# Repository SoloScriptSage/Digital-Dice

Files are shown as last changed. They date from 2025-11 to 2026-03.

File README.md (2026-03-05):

# 🎲 Digital Dice

A hardware random number generator built entirely from discrete logic ICs — no microcontroller, no code. Press the button, get a random number from 1 to 6 on a 7-segment display.

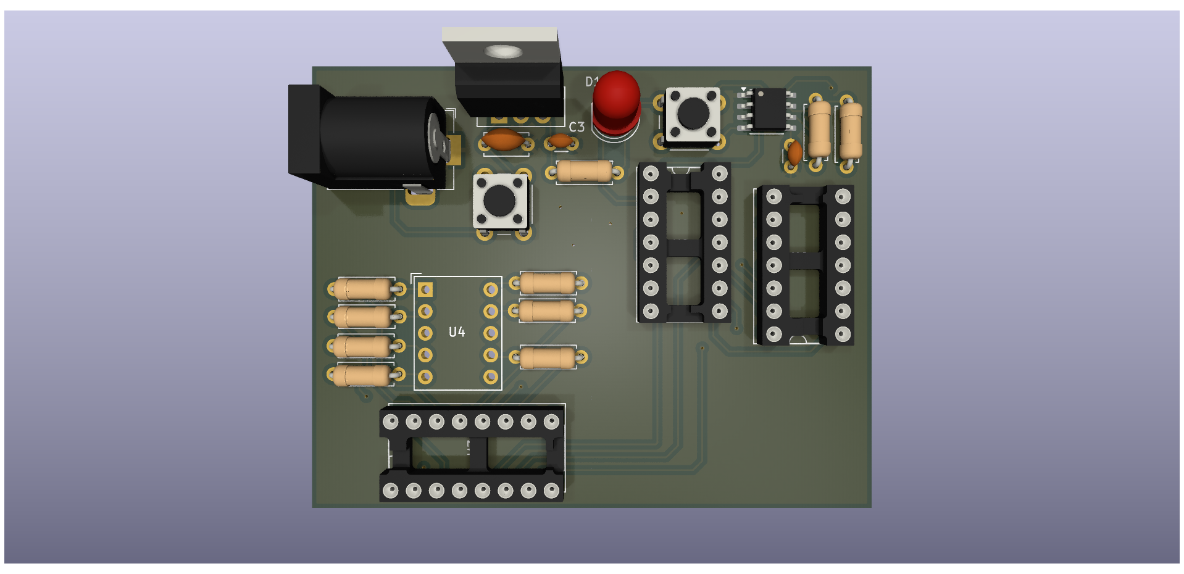
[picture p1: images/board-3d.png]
Schematic


---

## How It Works

The circuit is split into four sections:

```
[Power Supply] → [555 Timer Oscillator] → [74LS90 Counter] → [74LS47 BCD Decoder] → [7-Segment Display]
```

**1. Power Supply (LM7805)**
Accepts any DC input (7–35V via barrel jack) and regulates it down to a stable 5V. Decoupling capacitors filter noise on the supply line.

**2. Clock Generator (NE555 in astable mode)**
The 555 timer oscillates continuously, generating a fast clock signal. While the button is not pressed, the counter increments at high speed — too fast for the eye to track, which creates the randomness.

**3. Counter / Random Number Generator (74LS90)**
A 4-bit BCD counter that cycles 0→9. A NAND gate feedback loop (74LS11) resets it at 6, so it only counts 0–5 (displayed as 1–6). When the button is released, the counter freezes at whatever value it landed on.

**4. BCD Decoder + Display (74LS47 + SC39-11EWA)**
The 74LS47 converts the binary counter output into the 7 segment drive signals. A 220Ω current-limiting resistor protects the display segments.

---

## Components

| Component | Part | Purpose |
|---|---|---|
| U1 | NE555D | Astable oscillator (clock) |
| U2 | 74LS90 | 4-bit BCD counter |
| U3 | 74LS47 | BCD to 7-segment decoder |
| U4 | SC39-11EWA | Common cathode 7-segment display |
| U5 | LM7805 | 5V linear voltage regulator |
| U6A/D | 74LS11 | Triple 3-input AND gate (reset logic) |
| SW1 | SPST | Roll button |
| SW2 | SPST | Power switch |
| R1 | 10kΩ | 555 timing resistor |
| R5 | 220Ω | Display current limiter |
| R10 | 100kΩ | 555 timing resistor |
| J1 | Barrel Jack | DC power input |

---

## Schematic

Designed in **KiCad 9.0.2**. Full schematic and PCB layout files included in the repository.

---

## What I Learned

- Astable 555 timer configuration and RC timing calculations
- 4-bit BCD counter operation and modulo-N reset using gate feedback
- BCD to 7-segment decoding without a microcontroller
- PCB layout for mixed digital/analog circuits in KiCad

---

## Author

**Vladyslav Hirchuk** — [GitHub](https://github.com/SoloScriptSage) · [LinkedIn](https://linkedin.com/in/vladyslavhirchuk)

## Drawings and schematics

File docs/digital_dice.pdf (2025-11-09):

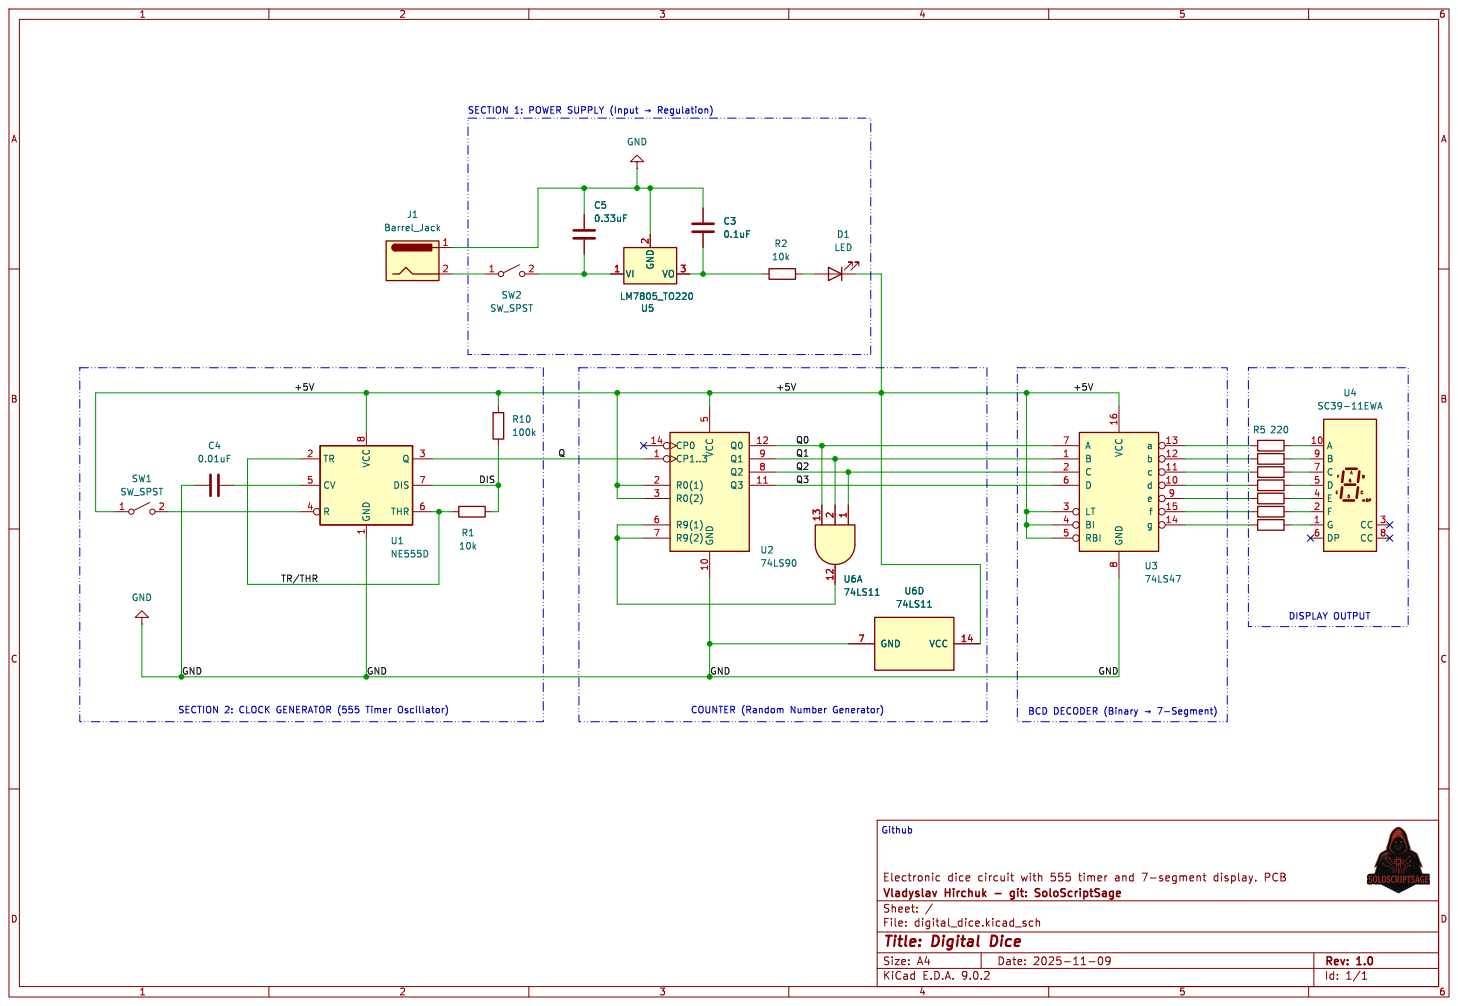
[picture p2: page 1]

SECTION 1: POWER SUPPLY (Input þÿ!’Regulation) COUNTER (Random Number Generator)

Id: 1/1 Title: Digital Dice

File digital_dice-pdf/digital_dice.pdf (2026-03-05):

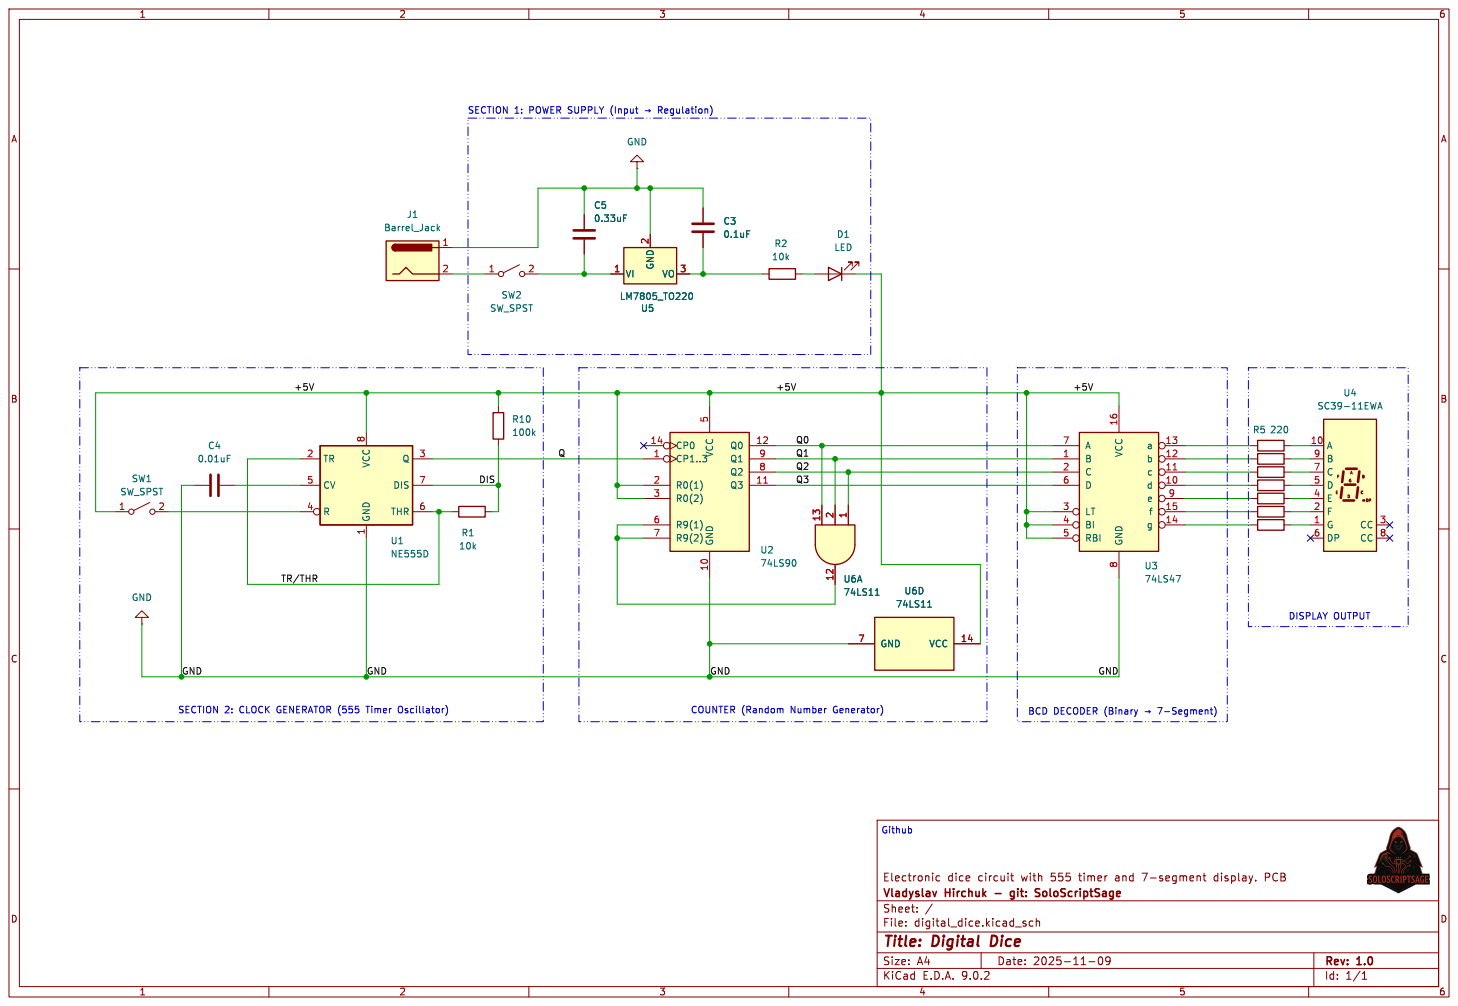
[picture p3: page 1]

Id: 1/1 Title: Digital Dice

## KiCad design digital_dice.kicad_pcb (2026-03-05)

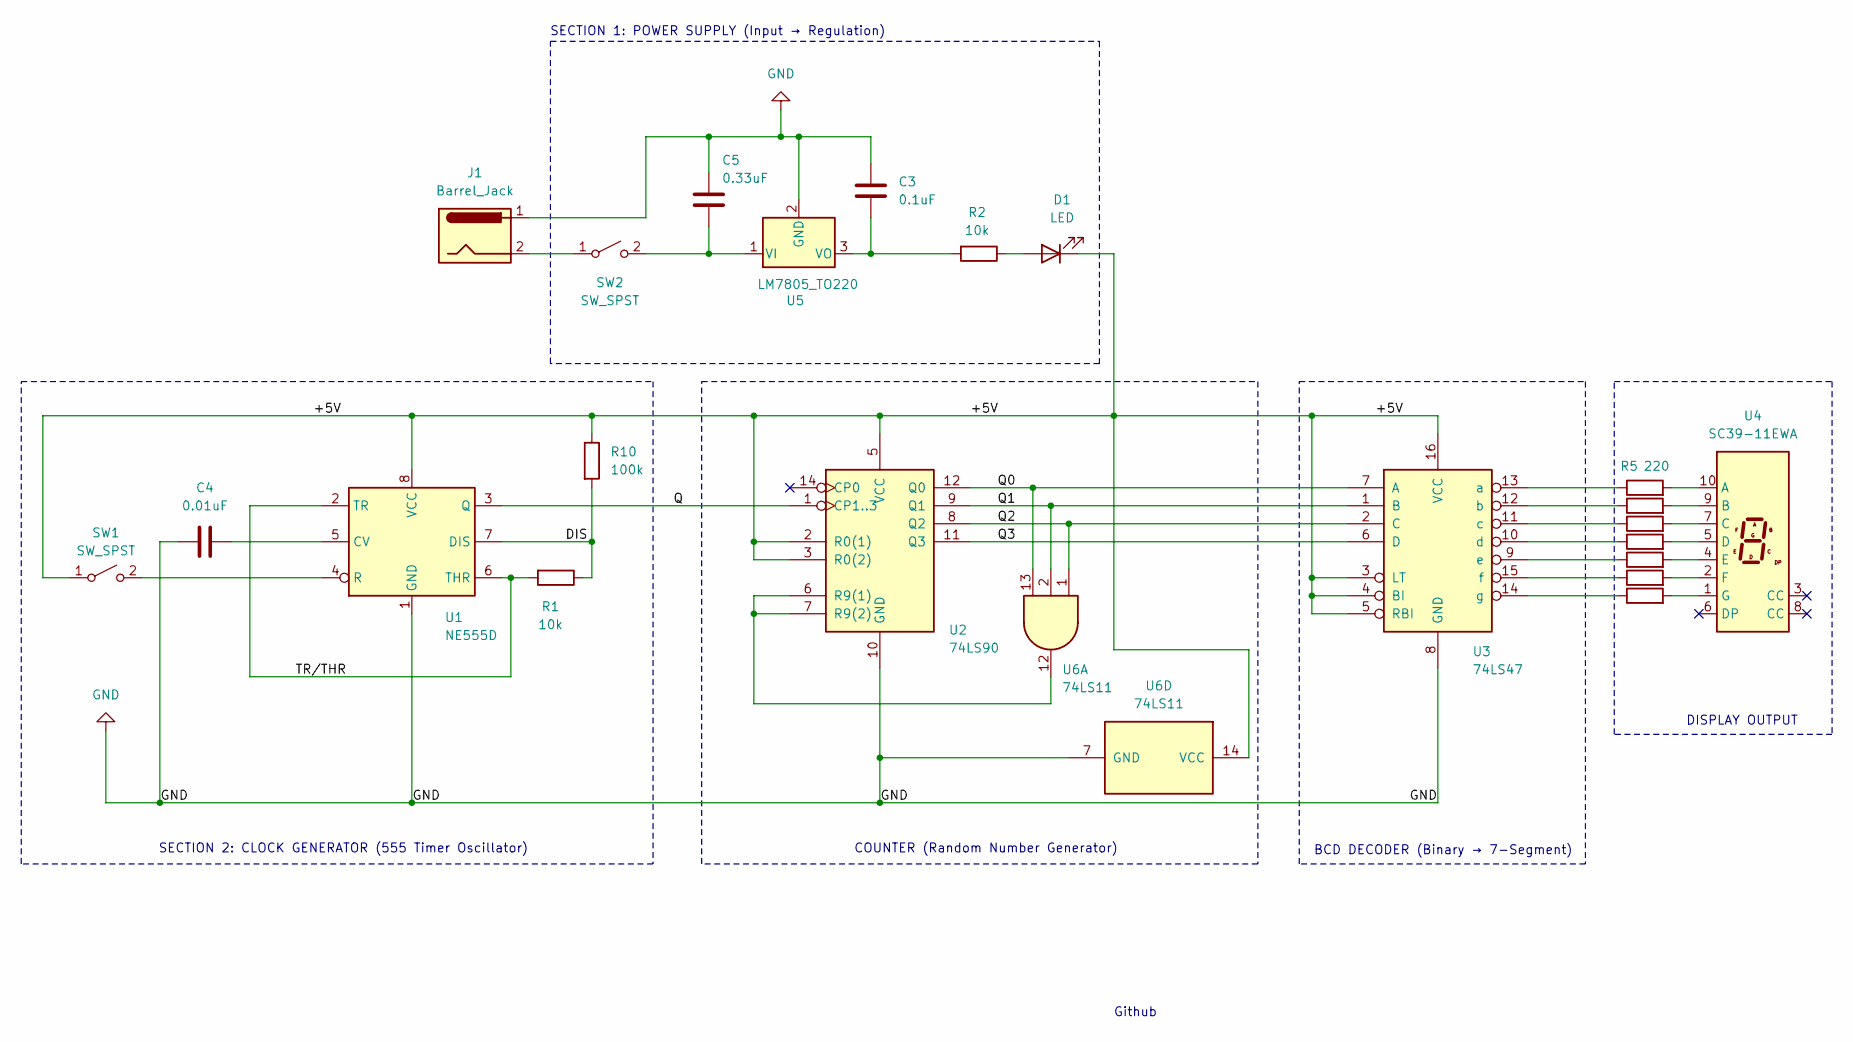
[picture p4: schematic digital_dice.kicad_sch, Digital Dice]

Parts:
C3: 0.1uF; C_Disc_D3.0mm_W1.6mm_P2.50mm
C4: 0.01uF; C_Disc_D3.0mm_W1.6mm_P2.50mm
C5: 0.33uF; C_Disc_D5.0mm_W2.5mm_P5.00mm
D1: LED; LED_D5.0mm
J1: Barrel_Jack; BarrelJack_Horizontal
R1, R2: 10k; R_Axial_DIN0207_L6.3mm_D2.5mm_P7.62mm_Horizontal
R3, R4, R5, R6, R7, R8, R9: 220; R_Axial_DIN0207_L6.3mm_D2.5mm_P7.62mm_Horizontal
R10: 100k; R_Axial_DIN0207_L6.3mm_D2.5mm_P7.62mm_Horizontal
SW1, SW2: SW_SPST; SW_PUSH_6mm
U1: NE555D; SOIC-8_3.9x4.9mm_P1.27mm
U2: 74LS90; DIP-14_W7.62mm_Socket
U3: 74LS47; DIP-16_W7.62mm_Socket
U4: SC39-11EWA; Sx39-1xxxxx
U5: LM7805_TO220; TO-220-3_Vertical
U6: 74LS11; DIP-14_W7.62mm_Socket

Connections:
/+5V: D1.1 (K), R10.1, SW1.1 (A), U1.8 (VCC), U2.2 (R0(1)), U2.3 (R0(2)), U2.5 (VCC), U3.3 (LT), U3.4 (BI), U3.5 (RBI), U3.16 (VCC), U6.14 (VCC)
/DIS: R1.1, R10.2, U1.7 (DIS)
/Q: U1.3 (Q), U2.1 (CP1..3)
/Q0: U2.12 (Q0), U3.7 (A), U6.13
/Q1: U2.9 (Q1), U3.1 (B), U6.2
/Q2: U2.8 (Q2), U3.2 (C), U6.1
/Q3: U2.11 (Q3), U3.6 (D)
/TR/THR: R1.2, U1.2 (TR), U1.6 (THR)
GND: C3.1, C4.1, C5.1, J1.1, U1.1 (GND), U2.10 (GND), U3.8 (GND), U5.2 (GND), U6.7 (GND)
unnamed: D1.2 (A), R2.1
unnamed: SW1.2 (B), U1.4 (R)
unnamed: J1.2, SW2.1 (A)
unnamed: C5.2, SW2.2 (B), U5.1 (VI)
unnamed: C4.2, U1.5 (CV)
unnamed: U2.6 (R9(1)), U2.7 (R9(2)), U6.12
unnamed: R5.1, U3.13 (a)
unnamed: R3.1, U3.12 (b)
unnamed: R4.1, U3.11 (c)
unnamed: R6.1, U3.10 (d)
unnamed: R7.1, U3.9 (e)
unnamed: R8.1, U3.15 (f)
unnamed: R9.1, U3.14 (g)
unnamed: R5.2, U4.10 (A)
unnamed: R3.2, U4.9 (B)
unnamed: R4.2, U4.7 (C)
unnamed: R6.2, U4.5 (D)
unnamed: R7.2, U4.4 (E)
unnamed: R8.2, U4.2 (F)
unnamed: R9.2, U4.1 (G)
unnamed: C3.2, R2.2, U5.3 (VO)

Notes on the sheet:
DISPLAY OUTPUT
BCD DECODER (Binary → 7-Segment)
SECTION 2: CLOCK GENERATOR (555 Timer Oscillator)
Github
COUNTER (Random Number Generator)
SECTION 1: POWER SUPPLY (Input → Regulation)

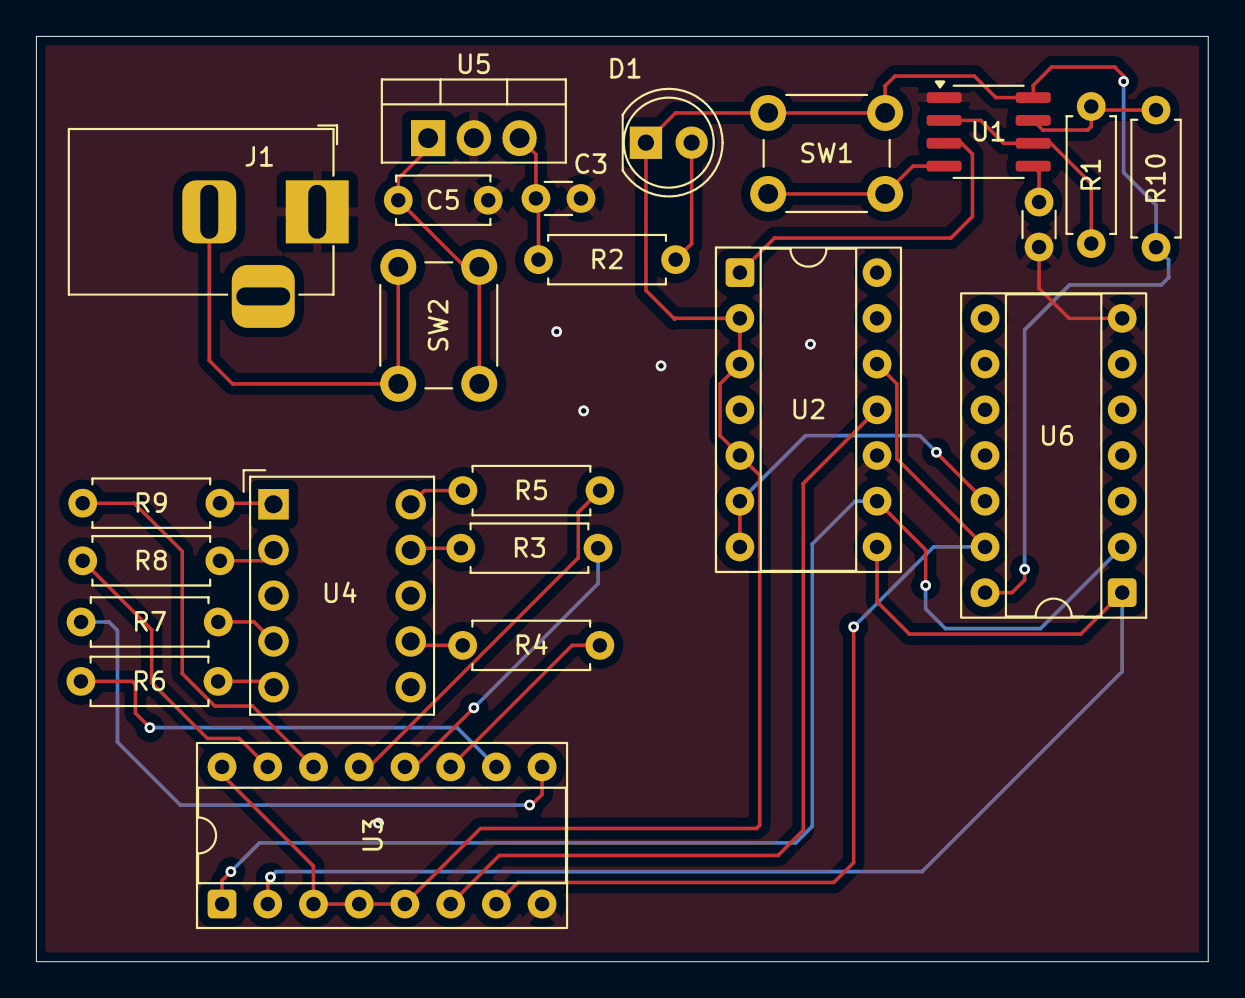
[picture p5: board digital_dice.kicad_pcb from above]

Board: 2 copper layers, 65.1 x 51.4 mm, 23 parts (0 on the bottom side), 30 nets.

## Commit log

2025-11-08 Restructure: move project files to root directory
    [digital_dice.kicad_pcb, digital_dice.kicad_sch]
2025-11-09 Final Touches:
    [digital_dice-B_Cu.gbr, digital_dice-B_Mask.gbr, digital_dice-B_Paste.gbr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]
2026-03-05 Update PCB layout
    [digital_dice.kicad_pcb]
